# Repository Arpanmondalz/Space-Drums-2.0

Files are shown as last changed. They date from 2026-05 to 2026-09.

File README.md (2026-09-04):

# Space Drums 2.0 Operating Guide

Reference for the air-drumming system: two ESP32-S3 sticks --> ESP32-S3 hub --> Python audio engine.

## 1. System overview

```
[Stick 0 / LEFT ]  ESP-NOW ->
                              foot pedal hub  -->  android/PC app
[Stick 1 / RIGHT]  ESP-NOW ->       
```

| File | Runs on | Purpose |
| :--- | :--- | :--- |
| `stick_firmware.ino` | Both sticks | IMU fusion, hit detection, calibration, battery |
| `spacedrums_2_hub.ino` | ESP32-S3 | ESP-NOW receiver, foot pedals, serial bridge |
| `audio_hub.py` | PC |Optional. Sample playback, kit UI, battery display. |
| `SpaceDrums.apk` | Android | Use this instead of the PC app. Sample playback, kit UI, battery display. |

---

## 2. Hardware

### 2.1 Stick pinout (ESP32-S3-MINI-1-N8)

| Function | GPIO | Notes |
| :--- | :--- | :--- |
| SPI MOSI / MISO / SCK | 35 / 37 / 36 | Shared by both IMUs |
| IMU1 CS (U5, tip) | 5 | ICM-42688-P |
| IMU2 CS (U4, base) | 9 | ICM-42688-P: **used for orientation and hit detection** |
| I2C SDA / SCL | 7 / 8 | MMC5983MA magnetometer + DRV2605L haptic |
| Status LED | 41 | Active high |
| PMIC KILL | 11 | Hold **HIGH** to keep power on (active-low kill, 0.6 V threshold) |
| PMIC INT | 12 | LTC2954 button press, active low |
| Battery sense | 4 | ADC1_CH3, R9/R10 = 100k/100k divider, C21 = 0.1 uF |

Only IMU2 (U4, near the base) drives orientation and swing detection. IMU1 is read but currently unused, it sees less useful gravity data mid-swing because it is further from the pivot.

### 2.2 Foot pedals (wired to the hub)

| Pedal | XIAO pin | GPIO |
| :--- | :--- | :--- |
| Left | D0 | 1 |
| Right | D1 | 2 |

Wire each momentary switch **between the pin and GND**. Firmware sets `INPUT_PULLUP`, so it is active-low.

Resistors: internal pull-ups alone are fine for short leads. For pedal-length cable, per channel add:

- **10 kΩ** pin 3V3 (swamps the weak ~45 kΩ internal pull-up)
- **100 nF** pin GND (~1 ms RC, kills noise spikes)
- optional **100 Ω** in series for ESD protection

---

## 3. Build and flash

### 3.1 Arduino IDE settings: sticks (ESP32-S3-MINI-1-N8)

| Setting | Value |
| :--- | :--- |
| **USB CDC On Boot** | **Enabled** |
| USB Mode | Hardware CDC and JTAG |
| Flash Size | 8MB (64Mb) |
| Partition Scheme | any 8MB scheme |
| PSRAM | **Disabled** (N8 has none) |

### 3.2 Per-stick edits

1. `STICK_ID` : `0` for left, `1` for right.
2. `hubAddress[]` : must match the MAC the hub prints at boot.

### 3.3 Order of operations

Flash the **hub first**, read its MAC from serial at 500000 baud, put that into both sticks, then flash the sticks.

---

## 4. Python setup

```powershell
pip install -r requirements.txt
python audio_hub.py
```

Set `COM_PORT` at the top of `audio_hub.py` to the **hub's** port.

Required samples in the same folder:

```
crash.wav  snare.wav  tom1.wav  tom2.wav  ride.wav  hihat.wav  floor_tom.wav
kick.wav   hihat_pedal.wav
```

A missing file falls back to a buzz instead of crashing.

Flags at the top of the file:

| Flag | Default | Effect |
| :--- | :--- | :--- |
| `SHOW_UI` | `True` | `False` = headless terminal mode |
| `CONSOLE_LOG` | `False` | Per-hit printing. Costs milliseconds on Windows — leave off while playing |

---

## 5. Everyday use

### 5.1 Power on

Hold the stick **pointing at where the snare will be** and press the power button.

| Stage | LED | Haptic |
| :--- | :--- | :--- |
| Settling (1.5 s) | solid | - |
| Calibrating | **5 Hz flash** | single click at start |
| Playing | 1 Hz heartbeat | double click when done |

Hold still through the flashing (~1.2 s). If you move, the window silently restarts and keeps flashing, just steady up.

**A long double-buzz instead of a double-click** means it gave up after 8 s and the zero is rough. Short-press to redo.

### 5.2 Re-zero mid-song

**Short-press** the power button. Same 1.5 s sequence. Use it any time the kit feels rotated.

**Long press still powers off** 

### 5.3 What calibration actually does

Sets pitch and yaw to zero **at wherever you are pointing**, plus re-measures gyro bias and builds the attitude from gravity. It is independent of magnetic north, so it works in any room, facing any direction.

---

## 6. Serial commands (stick, 115200)

> **Set the Serial Monitor line ending to "Newline"** — with "No line ending" nothing will run.

| Command | Effect |
| :--- | :--- |
| `help` | List commands |
| `status` | Live pitch/yaw, gyro bias, battery, mag calibration state |
| `cal` | Re-zero orientation (same as a short button press) |
| `magcal` | Run the 18 s figure-8 magnetometer calibration |
| `magclear` | Erase stored magnetometer calibration |
| `magyaw on` / `magyaw off` | Enable/disable the magnetometer yaw anchor |

The banner reprints whenever a serial monitor attaches, so you can connect at any time.

---

## 7. The figure-8 calibration

**Run once per stick. Only on fresh firmware install.**

It calibrates hard/soft-iron distortion from the stick's *own* magnetics: battery, haptic actuator, copper. 

### Procedure

1. Move away from speakers, PCs, steel furniture. Use a long USB cable, the PC itself is a disturber.
2. Type `magcal`. You get 18 seconds.
3. Trace slow figure-8s like you would do in a smartphone to calibrate the compass.
4. Read the verdict.

| Failure | Meaning | Fix |
| :--- | :--- | :--- |
| Not enough samples | Ended early | Keep moving the full 18 s |
| Poor coverage | Only one plane covered | Roll the stick as well as sweeping it |
| High residual | Nearby iron distorted the field | Move further away and retry |

**Bad data is never saved**, a FAIL leaves your previous calibration intact.

---

## 8. Drum layout

Zones are measured in degrees from your calibrated snare aim.

**Top row**: selected when pitch >= 25°, gated at +-110°:

| Aim | Drum |
| :--- | :--- |
| -110° ... -45° | Crash |
| -45° ... 0° | Tom 1 |
| 0° ... +45° | Tom 2 |
| +45° ... +110° | Ride |

**Bottom row**: pitch < 25°, gated at +-90°:

| Aim | Drum |
| :--- | :--- |
| -90° ... -30° | Hi-hat |
| -30° ... +30° | Snare |
| +30° ... +90° | Floor tom |

Outside the outer gates, nothing fires.

### Pedals

- **Right pedal** --> always kick.
- **Left pedal** --> kick *or* hi-hat close, selectable in the UI.

The firmware only reports *which pedal moved*; app decides the sound, so changing modes never needs a reflash.

---

## 9. Python UI

| Element | Meaning |
| :--- | :--- |
| Drum lights up | Cyan = left stick, orange = right stick; brightness scales with velocity |
| Pedal box | Flashes green; shows its current assignment |
| Battery bars | Green / amber <=45% / red <=20%; greyed and "old" if silent >60 s |
| Top-left text | Hub connection status (auto-reconnects every 2 s) |

| Key / action | Effect |
| :--- | :--- |
| Click left pedal box, or **L** | Toggle left pedal between hi-hat and kick |
| **Z** / **X** | Simulate left / right pedal (testing without hardware) |
| **ESC** or close window | Quit |

---

## 10. Serial protocol (hub → PC, 500000 baud)

| Line | Meaning |
| :--- | :--- |
| `H,<stick_id>,<drum_id>,<velocity>` | Hit. velocity 1-6 |
| `B,<stick_id>,<percent>,<millivolts>` | Battery, every 10 s per stick |
| `P,<pedal_id>[,<velocity>]` | Pedal. 0 = left, 1 = right. Velocity optional |

Drum IDs: `1` crash, `2` snare, `3` tom1, `4` tom2, `5` ride, `6` hihat, `7` floor_tom, `8` kick, `9` hihat_pedal.

ESP-NOW packet (7 bytes, packed, identical on stick and hub):

```
type | stick_id | drum_id | velocity | battery_pct | battery_mv(16-bit)
```

`type`: 0 = hit, 1 = battery, 2 = pedal (hub-generated only). The hub drops any packet whose length does not match, so mismatched firmware cannot produce garbage hits.

---

## 11. Tuning reference

All in the tunables block near the top of `stick_firmware.ino`.

### Feel / mapping

| Constant | Default | Raise it to... |
| :--- | :--- | :--- |
| `TOP_ROW_PITCH` | 25° | Require a higher aim for cymbals/toms |
| `TOP_YAW_CRASH` / `TOP_YAW_RIDE` | -+45° | Push crash/ride further out |
| `TOP_YAW_OUTER` | 110° | Widen the top catch area (lower to ~95 if you get phantom crashes) |
| `BOT_YAW_HIHAT` / `BOT_YAW_FLOOR` | -+30° | Widen the snare zone |
| `SWING_START_THRESHOLD` | 4000 | Require a harder swing to arm |
| `HIT_DECEL_THRESHOLD` | 3000 | Require sharper deceleration to fire |

### Orientation quality

| Constant | Default | Purpose |
| :--- | :--- | :--- |
| `ACC_KP` | 0.5 | Gravity correction strength (~2 s time constant) |
| `ZUPT_ALPHA` | 0.002 | How fast gyro bias re-learns while at rest |
| `MAG_YAW_GAIN` | 0.004 | Magnetometer yaw pull (~5 s time constant) |
| `CAL_GYRO_STILL_LSB` | 200 | Stillness required during calibration (~12 °/s) |

### Battery

| Constant | Default | Purpose |
| :--- | :--- | :--- |
| `VBAT_CAL_SCALE` | 1.0 | Trim if the reading disagrees with a multimeter |
| `VBAT_SEND_MS` | 10000 | Report interval |

### Hub

| Constant | Default | Purpose |
| :--- | :--- | :--- |
| `PEDAL_LOCKOUT_MS` | 35 | Debounce lock-out. Raise to 50 if a press produces repeats; stay under ~75 for fast double bass |
| `PEDAL_VELOCITY` | 6 | Pedal loudness (1-6) |

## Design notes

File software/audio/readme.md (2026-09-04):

# Audio samples for the python code.
These were taken from the open source drum samples at https://github.com/gregharvey/drum-samples

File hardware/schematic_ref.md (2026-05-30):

# Space Drums 2.0 — Schematic Reference Manual

This document serves as the technical reference for the Space Drums 2.0 printed circuit board schematic configuration. It inventories all integrated circuits, component blocks, communication buses, and hardware net structures.

---

## 1. Primary Integrated Circuit Inventory

| Reference Designator | Component Part Number | Manufacturer | Primary Function / Description |
| :--- | :--- | :--- | :--- |
| **U1** | ESP32-S3-MINI-1-N8 | Espressif Systems | Main Microcontroller Module (Wi-Fi/Bluetooth) |
| **U4** | ICM-42688-P | TDK InvenSense | 6-Axis Inertial Measurement Unit (Secondary) |
| **U5** | ICM-42688-P | TDK InvenSense | 6-Axis Inertial Measurement Unit (Primary) |
| **U7** | DRV2605L | Texas Instruments | Haptic Driver for ERM/LRA Actuators |
| **U8** | MMC5983MA | MEMSIC | 3-Axis Anisotropic Magnetometer (Compass) |
| **U10** | LTC2954 | Analog Devices | Pushbutton Power Benefit Controller |

---

## 2. Bus Architecture and Signal Routing

### 2.1 High-Speed Serial Peripheral Interface (SPI) Bus
The primary motion tracking sensors share a high-speed SPI bus to stream sensor data to the ESP32-S3 module.

* **Master Out Slave In (`SPI_MOSI`):** Routed to ESP32 pin **GPIO35**. Connects to Pin 13 (`SDI`) on U4 and U5.
* **Master In Slave Out (`SPI_MISO`):** Routed to ESP32 pin **GPIO37**. Connects to Pin 12 (`SDO`) on U4 and U5.
* **Serial Clock (`SPI_SCK`):** Routed to ESP32 pin **GPIO36**. Connects to Pin 11 (`SCLK`) on U4 and U5.

#### Dedicated Control Lines
* **U5 (IMU 1) Chip Select (`IMU1_CS`):** Routed to ESP32 pin **GPIO5**.
* **U5 (IMU 1) Hardware Interrupt (`IMU1_INT`):** Routed to ESP32 pin **GPIO6**.
* **U4 (IMU 2) Chip Select (`IMU2_CS`):** Routed to ESP32 pin **GPIO9**.
* **U4 (IMU 2) Hardware Interrupt (`IMU2_INT`):** Routed to ESP32 pin **GPIO10**.

### 2.2 Inter-Integrated Circuit (I2C) Bus
Auxiliary configuration, orientation, and haptic feedback devices share a standard I2C bus.

* **Serial Data (`SDA`):** Routed to ESP32 pin **GPIO7**. Connects to U7 (`SDA`) and U8 (`SDA`).
* **Serial Clock (`SCL`):** Routed to ESP32 pin **GPIO8**. Connects to U7 (`SCL`) and U8 (`SCL`).

#### Specific Hardware Configurations
* **U8 Magnetometer Interrupt:** The hardware interrupt pin on the MMC5983MA chip is unrouted in this schematic revision.
* **U7 Haptic Driver Trigger Mode:** The `IN/TRIG` pin on the DRV2605L chip is tied directly to system ground. Waveform playback execution is commanded entirely through software register writes over the I2C interface.

---

## 3. Power Control and Monitoring Architecture

### 3.1 Intelligent Power State Engine
The U10 LTC2954 controller handles system boot and power-down states via an external physical pushbutton interface.

* **Power Hold Signal (`KILL`):** Driven by ESP32 pin **GPIO11**. Must be asserted by firmware immediately during boot execution to lock the power delivery circuitry into an active state.
* **Power Warning Interrupt (`INT`):** Routed to ESP32 pin **GPIO12**. The U10 controller asserts this signal low when the physical power button is pressed, indicating that a shutdown sequence is requested.

### 3.2 Analogue Battery Measurement
The state-of-charge tracking mechanism monitors the lithium-ion polymer battery cells safely.

* **Battery Voltage Monitor (`VBAT_SENSE`):** Routed to ESP32 pin **GPIO4** (configured as an Analog-to-Digital Converter channel). 
* **Voltage Division Structure:** Resistors R9 and R10 form a scaling network, partnered with smoothing capacitor C21, to bring raw battery voltages down to safe operating limits for the microcontroller input pin.

---

## 4. Input, Output, and Interface Routing

### 4.1 Native USB Interface
* **USB Data Negative (`USB_D-`):** Routed through a protective series resistor inline to ESP32 pin **GPIO19**.
* **USB Data Positive (`USB_D+`):** Routed through a protective series resistor inline to ESP32 pin **GPIO20**.

### 4.2 Hardware User Interface
* **Boot Selection Mode:** Handled via manual tactile pushbutton SW2 and pull-up configuration resistor R5 connected directly to net `IO0` (ESP32 pin **GPIO0**).
* **Hardware Chip Reset:** Handled via manual tactile pushbutton SW1 connected directly to the `EN` pin of the ESP32 module, decoupled via the resistor-capacitor combination of R6 and C5.
* **Status Output Indication:** Driven by ESP32 pin **GPIO41** through current-limiting resistor R18 directly to the active-high status light-emitting diode designated as LED1.

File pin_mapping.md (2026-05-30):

# Space Drums 2.0 — Pin Mapping

This document details the hardware pin connections and definitions for the **Space Drums 2.0** hardware. 

**Target Microcontroller:** ESP32-S3-MINI-1-N8

## Hardware Notes

* **GPIO0:** Boot strap pin for download mode.
* **UART0:** Used for standard serial communication/flashing (`TXD0` = GPIO43, `RXD0` = GPIO44).
* **USB:** Native USB support is routed through GPIO19 (D-) and GPIO20 (D+).
* **Power:** `3V3` is the main module supply; `GND` is common ground.

---

## Pinout Table

| ESP32 Pin | Net / Component(s) | Description / Function |
| :--- | :--- | :--- |
| **GPIO0** | `IO0` / SW2 / R5 | Boot button / Download mode |
| **GPIO4** | `VBAT_SENSE` / R9, R10, C21 | Battery voltage ADC sense (via voltage divider) |
| **GPIO5** | `IMU1_CS` / U5 (ICM-42688-P) | SPI Chip Select for IMU 1 |
| **GPIO6** | `IMU1_INT` / U5 | Hardware interrupt from IMU 1 |
| **GPIO7** | `SDA` / U8, U7 | I2C Data (shared by Magnetometer & Haptic Driver) |
| **GPIO8** | `SCL` / U8, U7 | I2C Clock (shared by Magnetometer & Haptic Driver) |
| **GPIO9** | `IMU2_CS` / U4 (ICM-42688-P) | SPI Chip Select for IMU 2 |
| **GPIO10** | `IMU2_INT` / U4 | Hardware interrupt from IMU 2 |
| **GPIO11** | `KILL` / U10 (LTC2954) | Power-hold / kill line to power controller |
| **GPIO12** | `INT` / U10 (LTC2954) | Power controller interrupt to ESP32 |
| **GPIO19** | `USB_D-` | Native USB D− (through series resistor) |
| **GPIO20** | `USB_D+` | Native USB D+ (through series resistor) |
| **GPIO35** | `SPI_MOSI` | SPI MOSI (to both IMUs) |
| **GPIO36** | `SPI_SCK` | SPI Clock (to both IMUs) |
| **GPIO37** | `SPI_MISO` | SPI MISO (from both IMUs) |
| **GPIO41** | `LED1` / R18 | Status LED |
| **GPIO43** | `UART0_TX` / H1 | Serial TX / U0TXD |
| **GPIO44** | `UART0_RX` / H1 | Serial RX / U0RXD |

---

## Arduino IDE Pin Definitions

```cpp
// Space Drums 2.0 — ESP32-S3-MINI-1-N8 Pin Map

// --- System & Power ---
#define PIN_BOOT_BTN        GPIO_NUM_0     // BOOT button to GND
#define PIN_VBAT_SENSE      GPIO_NUM_4     // Battery divider ADC
#define PIN_PMIC_KILL       GPIO_NUM_11    // LTC2954 KILL
#define PIN_PMIC_INT        GPIO_NUM_12    // LTC2954 INT
#define PIN_STATUS_LED      GPIO_NUM_41    // Status indicator

// --- SPI Bus (IMUs) ---
#define PIN_SPI_MOSI        GPIO_NUM_35
#define PIN_SPI_MISO        GPIO_NUM_37
#define PIN_SPI_SCK         GPIO_NUM_36
#define PIN_IMU1_CS         GPIO_NUM_5     // ICM-42688-P (1)
#define PIN_IMU1_INT        GPIO_NUM_6
#define PIN_IMU2_CS         GPIO_NUM_9     // ICM-42688-P (2)
#define PIN_IMU2_INT        GPIO_NUM_10

// --- I2C Bus (Magnetometer & Haptics) ---
#define PIN_I2C_SDA         GPIO_NUM_7     // MMC5983MA + DRV2605L
#define PIN_I2C_SCL         GPIO_NUM_8

// --- USB & Serial ---
#define PIN_USB_DM          GPIO_NUM_19    // Native USB D-
#define PIN_USB_DP          GPIO_NUM_20    // Native USB D+
#define PIN_UART0_TX        GPIO_NUM_43    // H1 TX / U0TXD
#define PIN_UART0_RX        GPIO_NUM_44    // H1 RX / U0RXD

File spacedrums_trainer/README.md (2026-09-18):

# Space Drums Trainer

A gamified way to learn the Space Drums air-drumming kit. Notes fall down a
highway, you play them on the sticks and pedals, and the tempo climbs from a
crawl to full speed while you play.

For hardware, firmware and the serial protocol, see [README.md](README.md).

---

## 1. What it does

**Learn to Play** — twelve numbered levels, one standard groove each, from
quarter notes on the snare to a two-bar groove-and-fill. Reach 65% accuracy to
unlock the next level. Every run starts at half speed and ramps to the
groove's target tempo, so you are never thrown in cold.

**Learn Rhythms** — seven standalone grooves you can listen to first. Pick one,
choose your own starting BPM, and it ramps to full speed the same way.

**Custom Rhythms** — MIDI import. Coming soon.

### Reading the screen

| You see | It means |
| :--- | :--- |
| **Blue** note | play it with your **left hand** |
| **Red** note | play it with your **right hand** |
| **Amber** bar or band | a **foot** |
| Solid disc | a drum (snare, toms) |
| Ring | a cymbal (crash, hi-hat, ride) |
| Amber bar, right half | **kick** — right foot |
| Amber band labelled `LIFT`, left half | **lift the left foot** to open the hi-hat, put it back down at the top edge |
| Line joining two notes | play them **together** |
| Extra amber ring around a hi-hat | that hi-hat is **open** |

Lanes are only shown for the drums the groove actually uses, ordered
left-to-right to match where they sit in the air. The pads under the hit line
sit on two tiers: upper for the drums you reach up to, lower for the rest.

---

## 2. Install

You need **Python 3.10 or newer**. Only two packages are required:
`pygame-ce` and `pyserial`.

### Linux (Fedora)

```bash
sudo dnf install python3 python3-pip
cd /path/to/sd2
python3 -m venv .venv
source .venv/bin/activate
pip install --upgrade pip
pip install -r requirements.txt
```

Add yourself to the `dialout` group once so the app can open the hub without
root, then log out and back in:

```bash
sudo usermod -aG dialout $USER
```

### Windows

```powershell
cd C:\path\to\sd2
python -m venv .venv
.\.venv\Scripts\Activate.ps1
python -m pip install --upgrade pip
pip install -r requirements.txt
```

If PowerShell blocks the activate script, either run
`Set-ExecutionPolicy -Scope Process RemoteSigned` first, or skip activation and
call the interpreter directly as shown below.

### Drum samples

Nine `.wav` files go in an `audio/` folder next to this README:

```
audio/crash.wav   audio/snare.wav    audio/tom1.wav
audio/tom2.wav    audio/ride.wav     audio/floor_tom.wav
audio/kick.wav    audio/hihat_open.wav   audio/hihat_closed.wav
```

Any file that is missing falls back to a soft buzz and the app tells you which
ones it could not find, so a partial set still runs.

---

## 3. Run

Linux, with the venv activated:

```bash
python -m spacedrums_trainer
```

Windows, without activating:

```powershell
.\.venv\Scripts\python.exe -m spacedrums_trainer
```

### Options

| Flag | Effect |
| :--- | :--- |
| `--fullscreen` | start fullscreen (`F11` toggles at any time) |
| `--port /dev/ttyACM0` | skip auto-detect and use this serial port |
| `--no-metronome` | start with the click track off (`M` toggles) |
| `--no-bloom` | disable the glow pass on slow machines |

The hub is found automatically — the app scans the serial ports, prefers
USB CDC devices, and reconnects on its own if you unplug it. The status line at
the bottom of the home screen tells you what it found.

---

## 4. Controls

| Key | Action |
| :--- | :--- |
| Arrow keys | move around menus |
| `Enter` | choose / start |
| `Space` | in the rhythm list, listen to the highlighted groove |
| `Esc` | back, or quit from the home screen |
| `F11` | fullscreen |
| `M` | metronome on/off while playing |
| `F3` | frame rate and CPU cost |

You can also play without the hardware, which is handy for testing:

| Key | Drum |
| :--- | :--- |
| `A` `S` `D` `F` `G` `H` `J` | crash, hi-hat, tom 1, snare, tom 2, floor, ride |
| `Space` | kick |
| `Shift` (hold) | lift the hi-hat pedal |

---

## 5. How scoring works

Each note is judged on how close your hit was to its target time. The windows
are deliberately generous — air drumming has no rebound surface and this is a
beginner tool — and they shrink as the tempo climbs so they never overlap
neighbouring notes.

| Grade | Points |
| :--- | :--- |
| Perfect | 100 |
| Good | 75 |
| OK | 45 |
| Miss | 0 |

Accuracy is your points as a share of a perfect run. Stray hits that match no
note are counted and shown at the end, but they do not break your combo.

The open hi-hat band is guidance, not a graded note. The hub does not reliably
report pedal *releases*, so lifting the foot changes the hi-hat sound but is
never scored against you.

At the end you get accuracy, stars, XP, and a one-line read on your timing —
for example *"You are running 24 ms late"*. That last number is the most useful
thing on the screen.

**Stars:** 1 star at 65%, 2 at 80%, 3 at 92%.
**Unlock:** 65% clears a level.

---

## 6. Where your progress lives

```
~/.config/spacedrums/profile.json     XP, unlocked levels, best scores, streak
~/.config/spacedrums/settings.json    port, volume, metronome, input offset
```

Delete either file to reset. `settings.json` is written on first run and
accepts:

| Key | Default | Purpose |
| :--- | :--- | :--- |
| `port` | `null` | `null` means auto-detect |
| `baud` | `500000` | must match the hub |
| `volume` | `0.9` | master volume |
| `input_offset_ms` | `0` | raise it if your hits register late |
| `metronome` | `true` | click track |
| `lookahead_s` | `2.6` | how long notes are visible before they land |

---

## 7. Troubleshooting

**No hub found.** Check the cable, then `ls /dev/ttyACM*` on Linux or Device
Manager on Windows, and pass the port explicitly with `--port`. On Linux a
"permission denied" almost always means you are not in the `dialout` group yet.

**Nothing makes a sound.** The app prints which samples are missing on
startup. Check the `audio/` folder name and the nine filenames above.

**Notes feel consistently early or late.** Raise or lower `input_offset_ms` in
`settings.json`. Positive values compensate for hits arriving late.

**The window will not go fullscreen on Wayland.** Run with
`SDL_VIDEODRIVER=x11 python -m spacedrums_trainer`.

**Choppy animation.** Start with `--no-bloom`. Press `F3` to see the frame
cost.

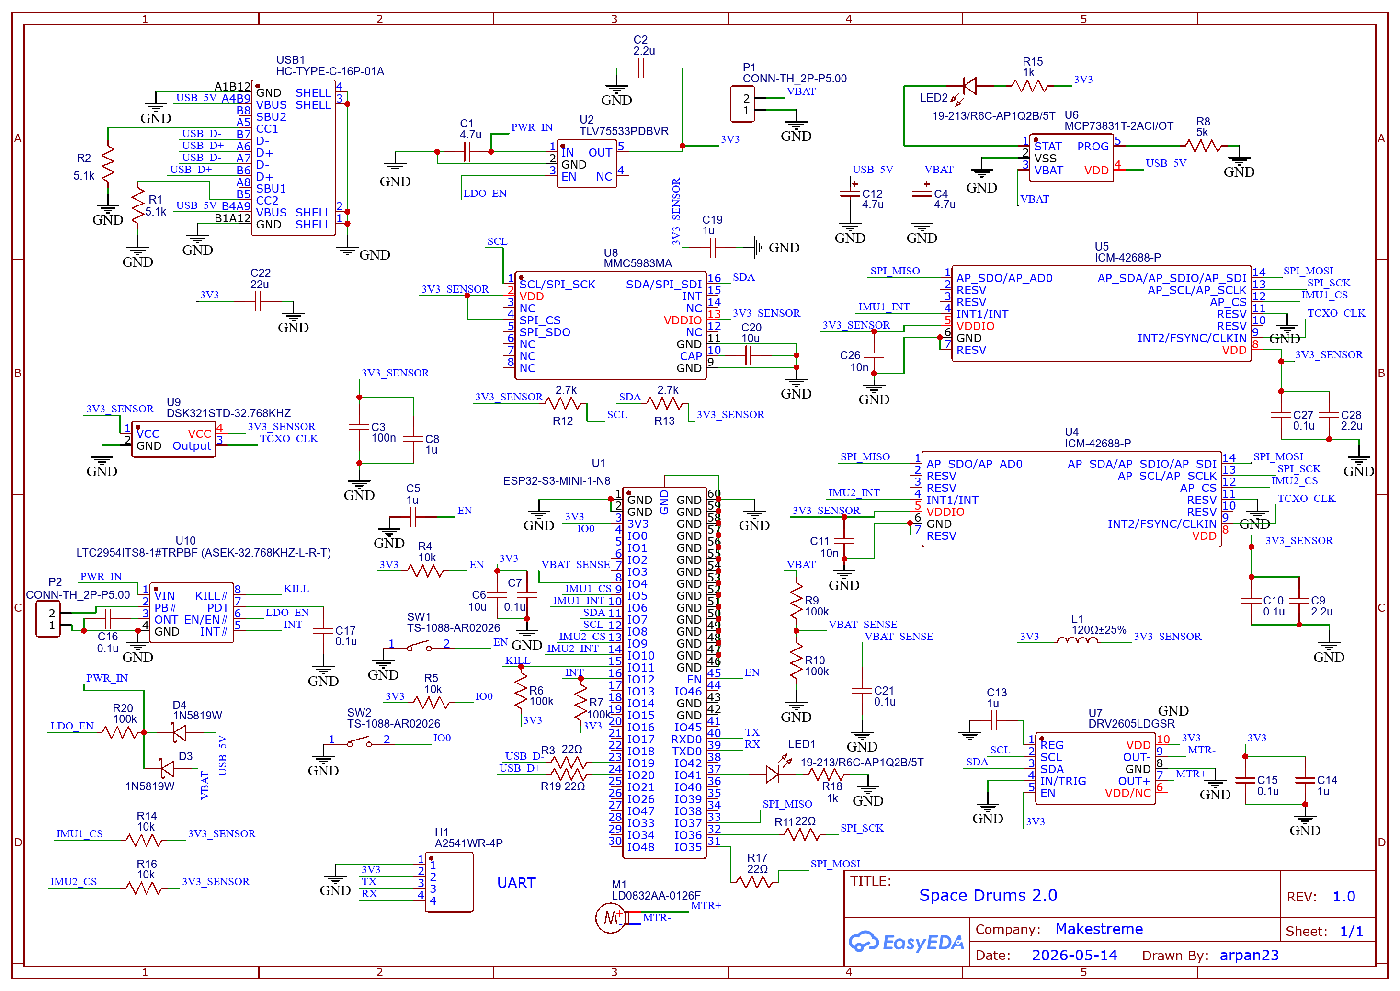
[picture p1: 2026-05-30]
hardware/EasyEDA_schematic.png

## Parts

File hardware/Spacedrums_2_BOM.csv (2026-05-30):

S/N | Designator* | Quantity* | Manufacturer Part Number* | Manufacturer | Package /Footprint | Description
1 | D3,D4 | 2 | 1N5819W | 晶导微电子 | SOD-123F_L2.8-W1.8-LS3.7-RD | 1N5819W
2 | C1 | 1 |  |  | C0603 | 4.7u
3 | C5,C13,C14,C19 | 4 |  |  | C0603 | 1u
4 | C12,C4 | 2 | CA45-A-16V-10uF-K | CEC(振华新云) | CAP-SMD_L3.2-W1.6-RD | 4.7u
5 | U10 | 1 | LTC2954ITS8-1#TRPBF | ADI(亚德诺)/LINEAR(凌特) | TSOT-23-8_L2.9-W1.6-P0.65-LS2.8-BL | LTC2954ITS8-1#TRPBF
6 | R20,R6,R7,R9,R10 | 5 |  |  | R0603 | 100k
7 | C2,C9,C28 | 3 |  |  | C0603 | 2.2u
8 | C6,C20 | 2 |  |  | C0603 | 10u
9 | C7,C10,C15,C16,C17,C21,C27 | 7 |  |  | C0603 | 0.1u
10 | C11,C26 | 2 |  |  | C0603 | 10n
11 | C3 | 1 | GCM033C71A104KE02D | muRata(村田) | C0201 | 100n
12 | C8 | 1 | GCM033C71A104KE02D | muRata(村田) | C0201 | 1u
13 | C22 | 1 | TCC0603X5R105K500CT | CCTC(三环) | C0603 | 22u
14 | H1 | 1 | A2541WR-4P | CJT(长江连接器) | HDR-TH_4P-P2.54-H-M-W10.3 | A2541WR-4P
15 | L1 | 1 | BLM18KG121TN1D | muRata(村田) | L0603 | 120Ω±25%
16 | LED1,LED2 | 2 | 19-213/R6C-AP1Q2B/5T | EVERLIGHT(亿光) | LED0603-FD | 19-213/R6C-AP1Q2B/5T
17 | M1 | 1 | LD0832AA-0126F | LEADER(立得) | MD-SMD_2P-LD0832AA-0126F | LD0832AA-0126F
18 | P1,P2 | 2 |  |  | HDR-TH-2P-P2.54-V-R02-C01 | CONN-TH_2P-P5.00
19 | R1,R2 | 2 |  |  | R0603 | 5.1k
20 | R3,R11,R17,R19 | 4 |  |  | R0603 | 22Ω
21 | R4,R5,R14,R16 | 4 |  |  | R0603 | 10k
22 | R8 | 1 |  |  | R0603 | 5k
23 | R12,R13 | 2 |  |  | R0603 | 2.7k
24 | R15,R18 | 2 |  |  | R0603 | 1k
25 | SW1,SW2 | 2 | TS-1088-AR02026 | XUNPU(讯普) | SW-SMD_L3.9-W3.0_TS-1088-AR02026 | TS-1088-AR02026
26 | U1 | 1 | ESP32-S3-MINI-1-N8 | ESPRESSIF(乐鑫) | BULETM-SMD_ESP32-S3-MINI-1-N8 | ESP32-S3-MINI-1-N8
27 | U2 | 1 | TLV75533PDBVR | TI(德州仪器) | SOT-23-5_L3.0-W1.7-P0.95-LS2.8-BR | TLV75533PDBVR
28 | U4,U5 | 2 | ICM-42688-P | TDK InvenSense(应美盛) | LGA-14_L3.0-W2.5-P0.50-TL | ICM-42688-P
29 | U6 | 1 | MCP73831T-2ACI/OT | MICROCHIP(美国微芯) | SOT-23-5_L3.0-W1.7-P0.95-LS2.8-BL | MCP73831T-2ACI/OT
30 | U7 | 1 | DRV2605LDGSR | TI(德州仪器) | VSSOP-10_L3.0-W3.0-P0.50-LS4.9-BL | DRV2605LDGSR
31 | U8 | 1 | MMC5983MA | MEMSIC(美新) | LGA-16_L3.0-W3.0-P0.50-BL_SQ | MMC5983MA
32 | U9 | 1 | DSK321STD-32.768Khz | null | OSC-SMD_4P-L3.2-W2.5-BL-1 | DSK321STD-32.768KHZ
33 | USB1 | 1 | HC-TYPE-C-16P-01A | HCTL(华灿天禄) | USB-C-SMD_HC-TYPE-C-16P-01A | HC-TYPE-C-16P-01A

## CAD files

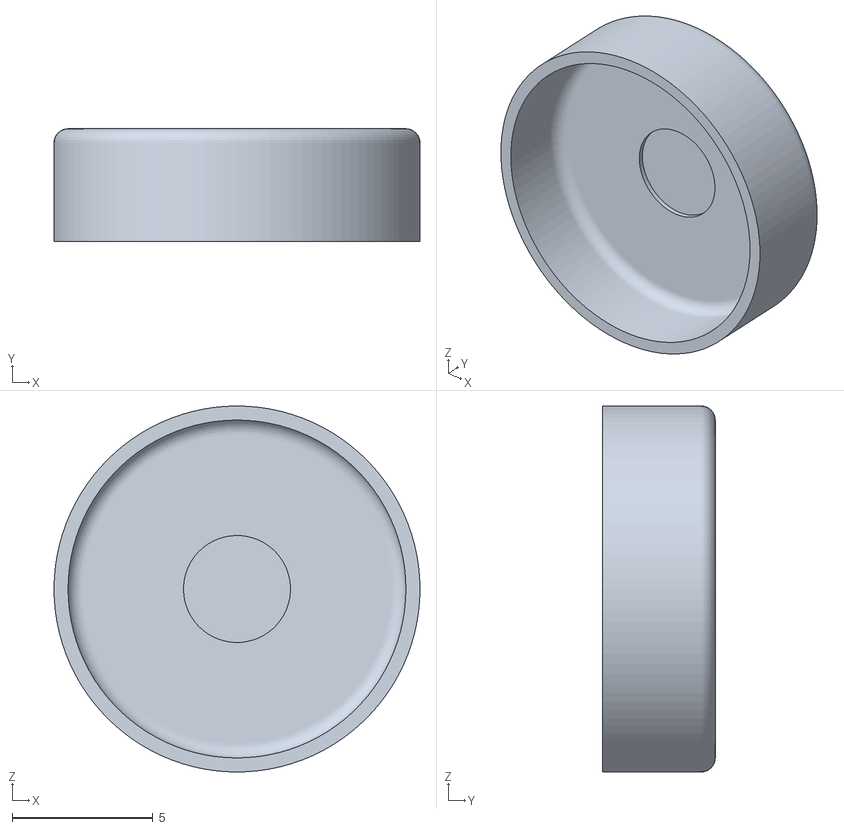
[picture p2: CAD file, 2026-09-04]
3d_prints/push_btn_cap.stl
13.0 x 4.00 x 13.0

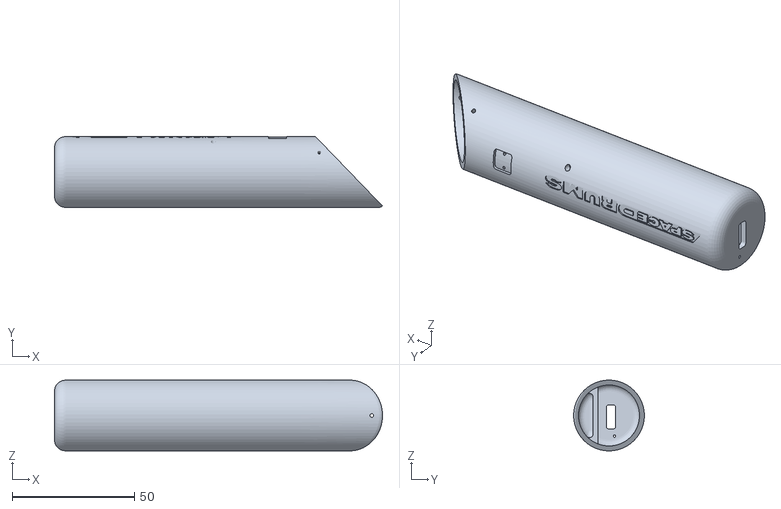
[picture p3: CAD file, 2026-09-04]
3d_prints/spacedrums2_base.stl
134.4 x 29.0 x 29.0

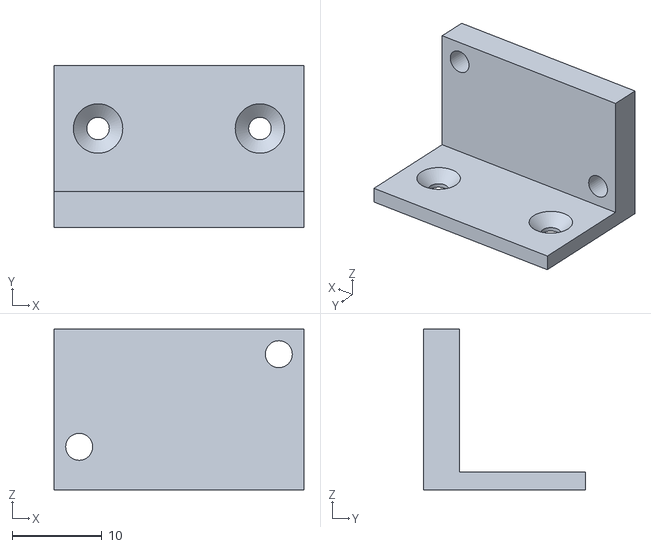
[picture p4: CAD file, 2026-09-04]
3d_prints/foot-bracket.stl
27.8 x 18.0 x 17.9

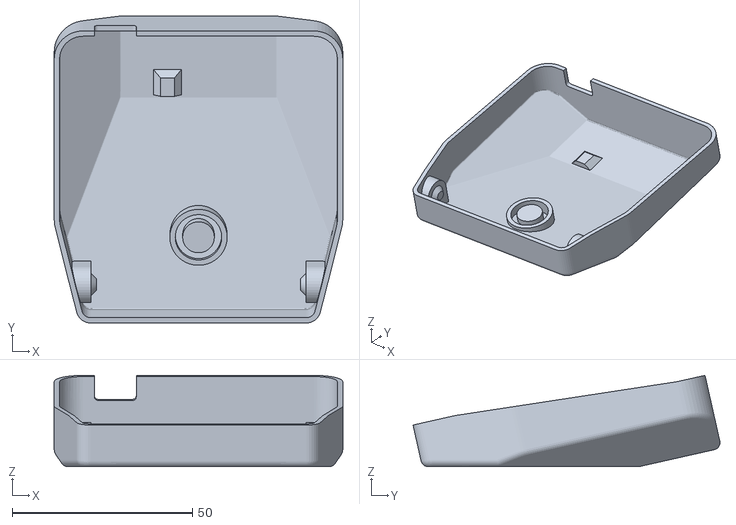
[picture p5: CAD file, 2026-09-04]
3d_prints/foot-top.stl
80.0 x 85.1 x 25.3

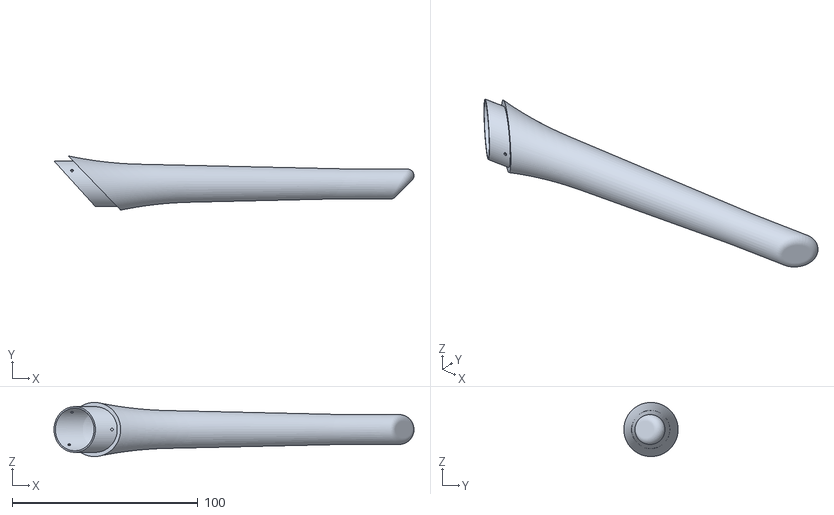
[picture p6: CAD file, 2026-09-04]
3d_prints/spacedrums2_tip.stl
193.8 x 29.2 x 29.2

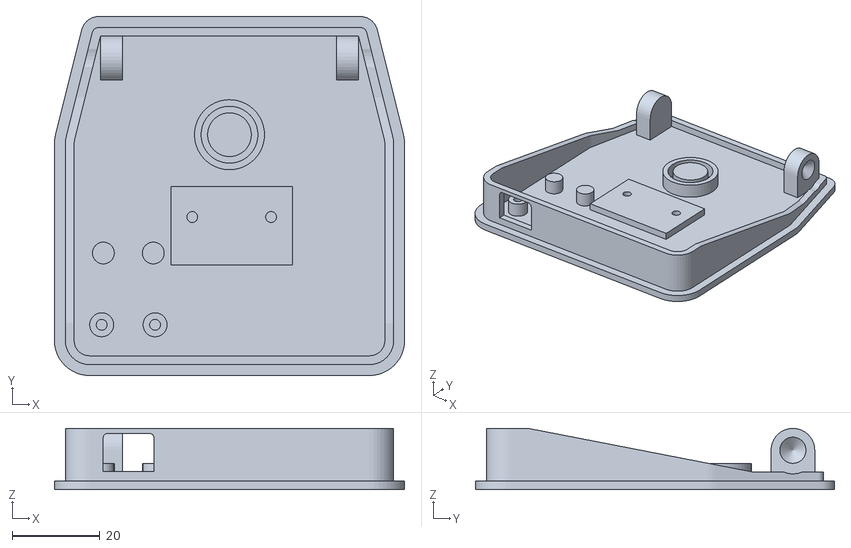
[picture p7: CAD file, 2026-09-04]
3d_prints/foot-base.stl
80.0 x 82.0 x 14.0

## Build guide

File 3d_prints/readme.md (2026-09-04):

# STL files for 3D printing

## Sticks
Base and Tip are separate. Can be screwed together using M2 screws after installing PCB.

## Foot Pedals
The design was originally created by Adafruit: https://learn.adafruit.com/usb-foot-switch-circuit-python/overview

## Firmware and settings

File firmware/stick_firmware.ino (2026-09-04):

#include <SPI.h>
#include <Wire.h>
#include <Preferences.h>
#include <WiFi.h>
#include <esp_now.h>
#include <freertos/FreeRTOS.h>
#include <freertos/task.h>
#include <freertos/semphr.h>
#include <freertos/queue.h>

// ==========================================
// CONFIGURATION
// ==========================================
//  XIAO ESP32S3 Hub MAC ADDRESS
uint8_t hubAddress[] = {0xE8, 0x06, 0x90, 0x9D, 0xA0, 0x68};

const uint8_t STICK_ID = 0; // 0 = Left Stick, 1 = Right Stick

// --- PIN CONFIGURATION ---
const int PIN_SPI_MOSI    = 35;
const int PIN_SPI_MISO    = 37;
const int PIN_SPI_SCK     = 36;
const int PIN_I2C_SDA     = 7;
const int PIN_I2C_SCL     = 8;
const int IMU1_CS         = 5;
const int IMU2_CS         = 9;
const int PIN_STATUS_LED  = 41;
const int PMIC_KILL       = 11;
const int PMIC_INT        = 12;
const int PIN_VBAT_SENSE  = 4;   // ADC1_CH3 - ADC1 stays usable while Wi-Fi is on

const uint8_t MMC5983_ADDR  = 0x30;
const uint8_t DRV2605_ADDR  = 0x5A;

// ==========================================
// FREERTOS OBJECTS
// ==========================================
SemaphoreHandle_t i2cMutex;
QueueHandle_t hitQueue;
QueueHandle_t hapticQueue;

// Must match struct_message in spacedrums_2_hub.ino byte for byte.
enum : uint8_t { MSG_HIT = 0, MSG_BATTERY = 1 };
struct __attribute__((packed)) StickPacket {
  uint8_t  type;
  uint8_t  stick_id;
  uint8_t  drum_id;      // MSG_HIT
  uint8_t  velocity;     // MSG_HIT
  uint8_t  battery_pct;  // MSG_BATTERY
  uint16_t battery_mv;   // MSG_BATTERY
};

// ==========================================
// TUNABLES
// ==========================================
// --- Orientation calibration (point at snare, hold still) ---
const uint32_t CAL_STABLE_WINDOW_MS = 1200;   // uninterrupted still time required
const uint32_t CAL_TIMEOUT_MS       = 8000;   // after this, accept best effort
const uint32_t BOOT_SETTLE_MS       = 1500;   // time to get into position after power-on
const int16_t  CAL_GYRO_STILL_LSB   = 200;    // ~12 deg/s per axis
const float    CAL_ACC_TOL_G        = 0.15f;

// --- AHRS ---
const float GYRO_LSB_TO_RADS = 0.001065264f;  // +/-2000 dps full scale
const float ACCEL_LSB_PER_G  = 2048.0f;       // +/-16 g full scale
const float ACC_KP           = 0.5f;          // gravity correction gain (~2 s time constant)
const float ACC_KI           = 0.02f;         // integral term: learns gyro offset while playing
const float ACC_GATE_G       = 0.20f;         // only trust accel within 1 g +/- this
const int16_t ACC_GATE_GYRO_LSB = 8000;       // ~490 deg/s, above this the swing dominates
const float ACC_KI_LIMIT_RADS = 0.09f;        // ~5 deg/s, beyond any plausible ICM-42688 offset

// --- Zero-rate update: in-run gyro bias tracking ---
// A stick in the hand is never truly still, so the old 3 deg/s gate almost never opened during
// a song. Looser gate plus a longer hold trades per-sample purity for actually firing.
const int16_t  ZUPT_GYRO_LSB  = 150;          // ~9 deg/s
const float    ZUPT_ACC_TOL_G = 0.10f;
const uint32_t ZUPT_HOLD_MS   = 400;
const float    ZUPT_ALPHA     = 0.0015f;

// --- Gyro bias vs die temperature ---
// The stick warms 10-15 C in the first minutes of play; that shift is the bulk of the yaw drift.
const uint32_t TCAL_SAMPLE_MS   = 20;
const float    TCAL_MIN_SPAN_C  = 4.0f;       // need this much temperature range to trust a slope
const uint32_t TCAL_MIN_SAMPLES = 400;
const uint32_t TCAL_SOLVE_EVERY = 200;
const float    TCAL_MAX_SLOPE   = 60.0f;      // LSB per C, ~3.7 deg/s per C

// --- IMU1 -> IMU2 gyro alignment, learned from ordinary playing ---
const float    ALIGN_MIN_RATE_LSB = 3000.0f;  // the fit is only observable while really rotating
const uint32_t ALIGN_DECIMATE     = 4;
const uint32_t ALIGN_MIN_SAMPLES  = 4000;
const uint32_t ALIGN_SOLVE_EVERY  = 1000;
const float    ALIGN_MAX_RAD      = 0.15f;    // >8.6 deg means a mounting rotation, not tolerance
const uint32_t ALIGN_IMPACT_BLANK_MS = 30;    // stick flex at contact is not a mounting error

// --- Stick geometry, measured from the tip (PCB sits at the base) ---
const float IMU1_TIP_M     = 0.190f;
const float IMU2_TIP_M     = 0.240f;
const float IMU_BASELINE_M = IMU2_TIP_M - IMU1_TIP_M;

// --- Velocity ---
// Loudness follows tip speed logarithmically, so the levels are spaced by equal speed ratios.
// These two bounds are the whole feel of the dynamics; nudge them if hits read hot or cold.
const float VEL_TIP_MIN_MPS    = 1.3f;
const float VEL_TIP_MAX_MPS    = 9.0f;
const float PIVOT_DEFAULT_M    = 0.08f;       // pivot-to-IMU2 for a wrist stroke, used until measured
const float PIVOT_MIN_M        = 0.00f;
const float PIVOT_MAX_M        = 0.55f;
const float PIVOT_ALPHA        = 0.25f;
const float PIVOT_MIN_RATE     = 8.0f;        // rad/s, below this w^2 is too small to divide by
const float PIVOT_SPREAD_TOL_M = 0.030f;      // measured IMU spacing must agree with IMU_BASELINE_M
const int16_t PIVOT_ACC_CLIP   = 30000;       // near +/-16 g the estimate is unusable

// Above ~1375 deg/s the gyro is heading for its +/-2000 dps rail, so fade over to the
// accelerometer pair, which measures the same rate by a route that cannot saturate.
const float   OMEGA_BLEND_LO = 24.0f;         // rad/s
const float   OMEGA_BLEND_HI = 33.0f;         // rad/s
const int16_t GYRO_CLIP_LSB  = 32000;

// --- Magnetometer yaw anchor (only active after a passing fig-8) ---
const float   MAG_YAW_GAIN      = 0.004f;     // per mag sample, ~5 s time constant
const float   MAG_FIELD_TOL     = 0.20f;      // reject sample if |B| off by >20%
const int16_t MAG_GATE_GYRO_LSB = 3000;       // ~180 deg/s

// --- Drum zones, in degrees of yaw/pitch relative to the snare aim ---
// Top and bottom rows have independent boundaries; the top row is spread wider
// because crash and ride sit further out than the toms.
const float TOP_ROW_PITCH  =  35.0f;   // Angle to trigger upper row. At or above this pitch, the upper row is selected
const float TOP_YAW_OUTER  = 110.0f;   // beyond this, no hit registers at all
const float TOP_YAW_CRASH  = -45.0f;   // left of this -> crash
const float TOP_YAW_CENTER =   0.0f;   // splits tom1 / tom2
const float TOP_YAW_RIDE   =  45.0f;   // right of this -> ride
const float BOT_YAW_OUTER  =  90.0f;
const float BOT_YAW_HIHAT  = -30.0f;   // left of this -> hihat
const float BOT_YAW_FLOOR  =  30.0f;   // right of this -> floor tom

// --- Battery monitoring ---
const float    VBAT_DIVIDER   = 2.0f;    // R9 = R10 = 100k, so Vbat = 2 x Vpin
const float    VBAT_CAL_SCALE = 1.0f;    // trim if it disagrees with a multimeter. Factor = (measured voltage)/(displayed voltage on hub)
const uint32_t VBAT_FIRST_MS  = 3000;
const uint32_t VBAT_SEND_MS   = 10000;
const uint32_t VBAT_QUIET_MS  = 1500;     // let the rail recover after a haptic pulse
const int      VBAT_SAMPLES   = 16;
const float    VBAT_EMA_ALPHA = 0.05f;

// --- Auto power-off ---
const uint32_t IDLE_POWEROFF_MS = 7200000UL;   // 2 h with the stick never leaving the ZUPT rest gate

// --- Fig-8 magnetometer calibration ---
const int      MAX_MAG_SAMPLES      = 300;
const uint32_t MAG_CAL_PERIOD_MS    = 60;
const uint32_t MAG_CAL_DURATION_MS  = 18000;
const int      MAG_CAL_MIN_SAMPLES  = 150;
const float    MAG_CAL_MAX_RESIDUAL = 0.08f;  // RMS sphere-fit error, fraction of radius
const float    MAG_CAL_MIN_COVERAGE = 0.50f;  // weakest axis chord vs mean chord

// ==========================================
// GLOBALS & STATE MACHINES
// ==========================================
Preferences prefs;
enum SystemState { STATE_BOOT_SETTLE, STATE_CALIBRATING, STATE_NORMAL, STATE_MAG_FIG8 };
volatile SystemState sysState = STATE_BOOT_SETTLE;
volatile bool buttonPressed = false;

unsigned long stateTimer = 0;
unsigned long lastLedToggle = 0;
bool ledState = false;

enum : uint8_t { IMU_TEMP = 0, IMU_AX, IMU_AY, IMU_AZ, IMU_GX, IMU_GY, IMU_GZ, IMU_FIELDS };

struct GyroTempCal {
  float slope[3];       // LSB per degC
  float refTemp;        // die temperature at which gyroBias* was captured
  bool  valid;
  double n, sT, sTT, sB[3], sTB[3];
  float tMin, tMax;
  uint32_t sinceSolve;
};
GyroTempCal tcal1 = {}, tcal2 = {};
volatile float dieTemp1 = 0, dieTemp2 = 0;
bool dieTempInit = false;

float accKiBias[3] = {0, 0, 0};               // rad/s, learned by the gravity correction

float alignDelta[3] = {0, 0, 0};              // small-angle rotation from IMU1 frame into IMU2 frame
volatile bool alignValid = false;
double alignAtA[3][3] = {{0}}, alignAtR[3] = {0};
uint32_t alignCount = 0, alignSinceSolve = 0, alignDecimate = 0;
volatile float gyroDisagree = 0;

float pivotToImu2 = PIVOT_DEFAULT_M;
volatile bool geomValid = false;              // set once the measured IMU spacing confirms the model
volatile uint32_t gyroClipCount = 0;
volatile float dbgTipSpeed = 0;
volatile bool driftCalDirty = false;
volatile uint32_t lastMotionMs = 0;

enum DrumState { STATE_IDLE, STATE_SWINGING, STATE_REFRACTORY };
DrumState stickState = STATE_IDLE;
const int16_t SWING_START_THRESHOLD = 4000;
const int16_t HIT_DECEL_THRESHOLD   = 3000;
int16_t peak_swing_velocity = 0; 
unsigned long hitTimer = 0;

float targetYawOffset = 0.0, targetPitchOffset = 0.0;

float gyroBiasX1 = 0, gyroBiasY1 = 0, gyroBiasZ1 = 0;
float gyroBiasX2 = 0, gyroBiasY2 = 0, gyroBiasZ2 = 0;
float magBiasX = 0, magBiasY = 0, magBiasZ = 0;
float magScaleX = 1.0, magScaleY = 1.0, magScaleZ = 1.0;
float magFieldRef = 0.0;                      // expected |B| after calibration
volatile bool magCalValid = false;
volatile bool magYawEnabled = true;

struct MagSample { float x, y, z; };
MagSample magBuffer[MAX_MAG_SAMPLES];
int magSampleCount = 0;
unsigned long lastMagSampleTime = 0;

// Calibrated magnetometer handoff: core 0 produces, core 1 consumes.
portMUX_TYPE magMux = portMUX_INITIALIZER_UNLOCKED;
float magBodyX = 0, magBodyY = 0, magBodyZ = 0;
volatile uint32_t magSeq = 0;

// Calibration result handshake: core 1 produces, core 0 reports.
volatile bool calCompleteFlag = false;
volatile bool calWasStable = false;

volatile float dbgPitch = 0, dbgYaw = 0;
uint8_t whoAmI1 = 0, whoAmI2 = 0;

float q0 = 1.0f, q1 = 0.0f, q2 = 0.0f, q3 = 0.0f;

SPISettings imuSpiSettings(16000000, MSBFIRST, SPI_MODE0);

// ==========================================
// INTERRUPTS & HARDWARE HELPERS
// ==========================================
void IRAM_ATTR isrCalibrate() { buttonPressed = true; }

void writeRegisterIMU(int csPin, uint8_t reg, uint8_t val) {
  SPI.beginTransaction(imuSpiSettings);
  digitalWrite(csPin, LOW); SPI.transfer(reg & 0x7F); SPI.transfer(val); digitalWrite(csPin, HIGH);
  SPI.endTransaction();
}

uint8_t readRegisterIMU(int csPin, uint8_t reg) {
  SPI.beginTransaction(imuSpiSettings);
  digitalWrite(csPin, LOW); SPI.transfer(reg | 0x80); uint8_t v = SPI.transfer(0x00); digitalWrite(csPin, HIGH);
  SPI.endTransaction();
  return v;
}

void selectBankIMU(int csPin, uint8_t bank) { writeRegisterIMU(csPin, 0x76, bank); }

// TEMP_DATA through GYRO_DATA_Z0 in one 14-byte burst; the die temperature drives bias compensation.
void readIMUBurst(int csPin, int16_t *out) {
  uint8_t buf[15] = {0};
  buf[0] = 0x1D | 0x80;
  SPI.beginTransaction(imuSpiSettings);
  digitalWrite(csPin, LOW);
  SPI.transferBytes(buf, buf, sizeof(buf));
  digitalWrite(csPin, HIGH);
  SPI.endTransaction();
  for (int i = 0; i < IMU_FIELDS; i++) out[i] = (int16_t)((buf[1 + 2 * i] << 8) | buf[2 + 2 * i]);
}

static inline float imuTempC(int16_t raw) { return (float)raw / 132.48f + 25.0f; }

void writeRegisterHaptic(uint8_t reg, uint8_t val) {
  if (xSemaphoreTake(i2cMutex, portMAX_DELAY)) {
    Wire.beginTransmission(DRV2605_ADDR); Wire.write(reg); Wire.write(val); Wire.endTransmission();
    xSemaphoreGive(i2cMutex);
  }
}

void hapticEffect(uint8_t e1, uint8_t e2) {
  writeRegisterHaptic(0x04, e1); writeRegisterHaptic(0x05, e2); writeRegisterHaptic(0x06, 0); writeRegisterHaptic(0x0C, 1);
}
void hapticCalStart()   { hapticEffect(1, 0); }    // single strong click
void hapticCalSuccess() { hapticEffect(10, 0); }   // double click
void hapticCalWarn()    { hapticEffect(14, 14); }  // long double buzz

void triggerHapticHit(int velocityBucket) {
  uint8_t effect = 1;
  switch(velocityBucket) {
    case 8: effect = 1; break; case 7: effect = 2; break; case 6: effect = 3; break; case 5: effect = 4; break;
    case 4: effect = 5; break; case 3: effect = 6; break; case 2: effect = 7; break; case 1: effect = 8; break;
  }
  writeRegisterHaptic(0x04, effect); writeRegisterHaptic(0x05, 0x00); writeRegisterHaptic(0x0C, 1);      
}

// Auto set/reset (CTRL0 bit5) cancels the sensor's own offset drift on every
// measurement; it must be re-asserted on each trigger write or it is cleared.
const uint8_t MMC_CTRL0_TM_AUTOSR = 0x21;

void initMagnetometer() {
  Wire.beginTransmission(MMC5983_ADDR); Wire.write(0x0A); Wire.write(0x02); Wire.endTransmission(); // 400 Hz BW, ~2 ms
  Wire.beginTransmission(MMC5983_ADDR); Wire.write(0x09); Wire.write(0x08); Wire.endTransmission(); // one-off SET
  delay(10);
}

void magStartMeasurement() {
  if (xSemaphoreTake(i2cMutex, pdMS_TO_TICKS(5))) {
    Wire.beginTransmission(MMC5983_ADDR); Wire.write(0x09); Wire.write(MMC_CTRL0_TM_AUTOSR); Wire.endTransmission();
    xSemaphoreGive(i2cMutex);
  }
}

bool magFetchIfReady(float &mx, float &my, float &mz) {
  bool ok = false;
  if (xSemaphoreTake(i2cMutex, pdMS_TO_TICKS(5))) {
    Wire.beginTransmission(MMC5983_ADDR); Wire.write(0x08); Wire.endTransmission();
    Wire.requestFrom(MMC5983_ADDR, (uint8_t)1);
    if (Wire.available() && (Wire.read() & 0x01)) {
      Wire.beginTransmission(MMC5983_ADDR); Wire.write(0x00); Wire.endTransmission();
      Wire.requestFrom(MMC5983_ADDR, (uint8_t)6);
      if (Wire.available() >= 6) {
        uint32_t rawX = (Wire.read() << 10) | (Wire.read() << 2);
        uint32_t rawY = (Wire.read() << 10) | (Wire.read() << 2);
        uint32_t rawZ = (Wire.read() << 10) | (Wire.read() << 2);
        mx = (float)((long)rawX - 131072); my = (float)((long)rawY - 131072); mz = (float)((long)rawZ - 131072);
        ok = true;
      }
    }
    xSemaphoreGive(i2cMutex);
  }
  return ok;
}

// Blocking variant, only used during the fig-8 sweep where no hits are being timed.
bool readMagnetometer(float &mx, float &my, float &mz) {
  magStartMeasurement();
  for (int i = 0; i < 20; i++) {
    delayMicroseconds(500);
    if (magFetchIfReady(mx, my, mz)) return true;
  }
  return false;
}

// ==========================================
// BATTERY
// ==========================================
uint16_t readBatteryMillivolts() {
  uint32_t sum = 0;
  for (int i = 0; i < VBAT_SAMPLES; i++) sum += analogReadMilliVolts(PIN_VBAT_SENSE);
  float pinMv = (float)sum / VBAT_SAMPLES;
  return (uint16_t)(pinMv * VBAT_DIVIDER * VBAT_CAL_SCALE);
}

// 1S LiPo discharge curve; a linear voltage-to-percent map is badly wrong in the flat middle.
uint8_t batteryPercent(uint16_t mv) {
  static const uint16_t curveMv[]  = {3270,3610,3690,3710,3730,3750,3770,3790,3800,3820,3840,
                                      3850,3870,3910,3950,3980,4020,4080,4110,4150,4200};
  static const uint8_t  curvePct[] = {   0,   5,  10,  15,  20,  25,  30,  35,  40,  45,  50,
                                        55,  60,  65,  70,  75,  80,  85,  90,  95, 100};
  const int n = sizeof(curvePct) / sizeof(curvePct[0]);
  if (mv <= curveMv[0]) return 0;
  if (mv >= curveMv[n - 1]) return 100;
  for (int i = 1; i < n; i++) {
    if (mv < curveMv[i]) {
      float f = (float)(mv - curveMv[i - 1]) / (float)(curveMv[i] - curveMv[i - 1]);
      return (uint8_t)(curvePct[i - 1] + f * (curvePct[i] - curvePct[i - 1]) + 0.5f);
    }
  }
  return 100;
}

void loadMagCalibration() {
  prefs.begin("drum_cal", true);
  magBiasX = prefs.getFloat("magBiasX", 0.0); magBiasY = prefs.getFloat("magBiasY", 0.0); magBiasZ = prefs.getFloat("magBiasZ", 0.0);
  magScaleX = prefs.getFloat("magScaleX", 1.0); magScaleY = prefs.getFloat("magScaleY", 1.0); magScaleZ = prefs.getFloat("magScaleZ", 1.0);
  magFieldRef = prefs.getFloat("magField", 0.0);
  magCalValid = prefs.getBool("magValid", false);
  magYawEnabled = prefs.getBool("magYaw", true);
  prefs.end();
}

// Learned, part-specific and stable across sessions: gyro bias-vs-temperature slopes and the
// small mounting misalignment between the two IMUs.
void loadDriftCalibration() {
  prefs.begin("drum_cal", true);
  tcal1.slope[0] = prefs.getFloat("t1sx", 0.0f); tcal1.slope[1] = prefs.getFloat("t1sy", 0.0f); tcal1.slope[2] = prefs.getFloat("t1sz", 0.0f);
  tcal2.slope[0] = prefs.getFloat("t2sx", 0.0f); tcal2.slope[1] = prefs.getFloat("t2sy", 0.0f); tcal2.slope[2] = prefs.getFloat("t2sz", 0.0f);
  tcal1.valid = prefs.getBool("t1v", false);
  tcal2.valid = prefs.getBool("t2v", false);
  alignDelta[0] = prefs.getFloat("algx", 0.0f); alignDelta[1] = prefs.getFloat("algy", 0.0f); alignDelta[2] = prefs.getFloat("algz", 0.0f);
  alignValid = prefs.getBool("algv", false);
  prefs.end();
}

void saveDriftCalibration() {
  prefs.begin("drum_cal", false);
  prefs.putFloat("t1sx", tcal1.slope[0]); prefs.putFloat("t1sy", tcal1.slope[1]); prefs.putFloat("t1sz", tcal1.slope[2]);
  prefs.putFloat("t2sx", tcal2.slope[0]); prefs.putFloat("t2sy", tcal2.slope[1]); prefs.putFloat("t2sz", tcal2.slope[2]);
  prefs.putBool("t1v", tcal1.valid); prefs.putBool("t2v", tcal2.valid);
  prefs.putFloat("algx", alignDelta[0]); prefs.putFloat("algy", alignDelta[1]); prefs.putFloat("algz", alignDelta[2]);
  prefs.putBool("algv", alignValid);
  prefs.end();
}

// Least-squares sphere fit: solves A*p = b for p = [2cx, 2cy, 2cz, r^2-|c|^2].
static bool solveSphere(double A[4][5], double out[4]) {
  for (int i = 0; i < 4; i++) {
    int piv = i;
    for (int r = i + 1; r < 4; r++) if (fabs(A[r][i]) > fabs(A[piv][i])) piv = r;
    if (fabs(A[piv][i]) < 1e-12) return false;
    if (piv != i) for (int c = 0; c < 5; c++) { double t = A[i][c]; A[i][c] = A[piv][c]; A[piv][c] = t; }
    for (int r = 0; r < 4; r++) {
      if (r == i) continue;
      double f = A[r][i] / A[i][i];
      for (int c = i; c < 5; c++) A[r][c] -= f * A[i][c];
    }
  }
  for (int i = 0; i < 4; i++) out[i] = A[i][4] / A[i][i];
  return true;
}

static bool solve3x3(double A[3][4], double out[3]) {
  for (int i = 0; i < 3; i++) {
    int piv = i;
    for (int r = i + 1; r < 3; r++) if (fabs(A[r][i]) > fabs(A[piv][i])) piv = r;
    if (fabs(A[piv][i]) < 1e-9) return false;
    if (piv != i) for (int c = 0; c < 4; c++) { double t = A[i][c]; A[i][c] = A[piv][c]; A[piv][c] = t; }
    for (int r = 0; r < 3; r++) {
      if (r == i) continue;
      double f = A[r][i] / A[i][i];
      for (int c = i; c < 4; c++) A[r][c] -= f * A[i][c];
    }
  }
  for (int i = 0; i < 3; i++) out[i] = A[i][3] / A[i][i];
  return true;
}
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
void loop() { vTaskDelete(NULL); }

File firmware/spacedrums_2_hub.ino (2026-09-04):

#include <esp_now.h>
#include <WiFi.h>
#include <freertos/FreeRTOS.h>
#include <freertos/queue.h>

// --- Foot pedals: momentary switch from pin to GND, internal pull-up ---
const int PIN_PEDAL_LEFT  = 1;   // XIAO D0 / GPIO1
const int PIN_PEDAL_RIGHT = 2;   // XIAO D1 / GPIO2
const int PEDAL_PINS[2]   = {PIN_PEDAL_LEFT, PIN_PEDAL_RIGHT};
const uint32_t PEDAL_DEBOUNCE_MS = 8;  // report the first edge, then ignore contact bounce
const uint8_t  PEDAL_VELOCITY    = 6;  // plain switches, no velocity sensing

// Both edges are reported now: in hi-hat mode the PC uses the held state to
// pick hihat_closed.wav vs hihat_open.wav for stick hits.
bool     pedalPressed[2]   = {false, false};
uint32_t pedalChangedMs[2] = {0, 0};

// Must match StickPacket in spacedrums_2.ino byte for byte.
// The sticks only ever send MSG_HIT / MSG_BATTERY; pedals are read here.
enum : uint8_t { MSG_HIT = 0, MSG_BATTERY = 1, MSG_PEDAL = 2 };
typedef struct __attribute__((packed)) struct_message {
    uint8_t  type;
    uint8_t  stick_id;
    uint8_t  drum_id;
    uint8_t  velocity;
    uint8_t  battery_pct;
    uint16_t battery_mv;
} struct_message;

// Create a queue to hold up to 20 rapid-fire hits
QueueHandle_t hubQueue;

// Polled instead of interrupt-driven: a bouncing contact can no longer latch
// the wrong open/closed state, the next poll re-reads the settled level.
void pollPedals() {
    uint32_t now = millis();
    for (uint8_t i = 0; i < 2; i++) {
        bool pressed = (digitalRead(PEDAL_PINS[i]) == LOW);
        if (pressed == pedalPressed[i]) continue;
        if (now - pedalChangedMs[i] < PEDAL_DEBOUNCE_MS) continue;

        pedalChangedMs[i] = now;
        pedalPressed[i] = pressed;

        Serial.print("P,");
        Serial.print(i);
        Serial.print(",");
        Serial.print(PEDAL_VELOCITY);
        Serial.print(",");
        Serial.println(pressed ? 1 : 0);
    }
}

// ESP32 Core v3.x Callback
void OnDataRecv(const esp_now_recv_info *info, const uint8_t *incomingData, int len) {
    if (len != (int)sizeof(struct_message)) return;
    struct_message hit;
    memcpy(&hit, incomingData, sizeof(hit));
    
    // OFF-LOAD TO QUEUE INSTANTLY! DO NOT SERIAL.PRINT HERE!
    // This frees the Wi-Fi stack in ~1 microsecond to catch the other stick's packet.
    xQueueSend(hubQueue, &hit, 0);
}

void setup() {
    // 80 MHz is the Wi-Fi minimum and leaves the 80 MHz APB clock (and the UART
    // baud rate) untouched, but runs the board noticeably cooler.
    setCpuFrequencyMhz(80);

    Serial.begin(500000);
    WiFi.mode(WIFI_STA);

    // Initialize the FreeRTOS Queue
    hubQueue = xQueueCreate(20, sizeof(struct_message));

    pinMode(PIN_PEDAL_LEFT, INPUT_PULLUP);
    pinMode(PIN_PEDAL_RIGHT, INPUT_PULLUP);

    delay(2000);
    Serial.print("HUB MAC ADDRESS: ");
    Serial.println(WiFi.macAddress());

    if (esp_now_init() != ESP_OK) {
        Serial.println("Error initializing ESP-NOW");
        return;
    }
    
    esp_now_register_recv_cb(OnDataRecv);
}

void loop() {
    struct_message pkt;

    // Wake at least once per tick so the pedals are polled promptly, but return
    // instantly whenever a stick packet is waiting.
    if (xQueueReceive(hubQueue, &pkt, pdMS_TO_TICKS(1)) == pdPASS) {
        // Safe to take our time printing here, the Wi-Fi task is untouched
        if (pkt.type == MSG_HIT) {
            Serial.print("H,");
            Serial.print(pkt.stick_id);
            Serial.print(",");
            Serial.print(pkt.drum_id);
            Serial.print(",");
            Serial.println(pkt.velocity);
        } else if (pkt.type == MSG_BATTERY) {
            Serial.print("B,");
            Serial.print(pkt.stick_id);
            Serial.print(",");
            Serial.print(pkt.battery_pct);
            Serial.print(",");
            Serial.println(pkt.battery_mv);
        }
    }

    pollPedals();
}

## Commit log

2026-05-30 Added pin mapping for schematic
2026-05-30 Add schematic reference manual for Space Drums 2.0
    This document serves as a technical reference for the Space Drums 2.0 schematic, detailing the integrated circuits, bus architecture, power control, and interface routing.
2026-05-30 uploaded schematic files
    [PickAndPlace_PCB_spacedrums_v2_2_2026-05-30.csv, Spacedrums_2_BOM.csv]
2026-05-30 Add gerber_ref.md for Gerber file documentation
2026-05-30 Added gerber
    [Drill_NPTH_Through.DRL, Drill_PTH_Through.DRL, Drill_PTH_Through_Via.DRL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]
2026-09-04 Revise README for Space Drums 2.0 Operating Guide
    Updated the README to include an operating guide for Space Drums 2.0, detailing system overview, hardware specifications, build instructions, Python setup, everyday use, and calibration procedures.
2026-09-04 Add pin mapping documentation for Space Drums 2.0
    This document provides detailed information on the pin mapping for the Space Drums 2.0 hardware, including GPIO assignments and their functions.
2026-09-04 Create README for 3D printing STL files
    Added information about sticks and foot pedals for 3D printing.
2026-09-04 Create readme.md for audio samples
    Added a readme file for audio samples with source information.
